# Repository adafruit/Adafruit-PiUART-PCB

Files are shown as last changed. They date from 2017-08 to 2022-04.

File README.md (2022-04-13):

## Adafruit PiUART PCB

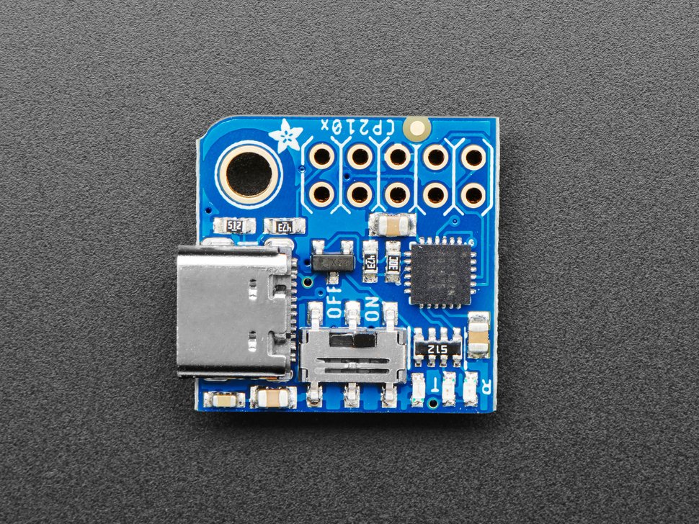
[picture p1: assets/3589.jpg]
<a href="http://www.adafruit.com/products/3589"><br/>
Click here to purchase one from the Adafruit shop</a>

PCB files for the Adafruit PiUART PCB. Format is EagleCAD schematic and board layout

For more details, check out the product page at
* http://www.adafruit.com/product/3589

### Description

Here's another super handy add-on for your Raspberry Pi computer, perfect for 'head-less' setups! The PiUART adds a USB Type-C to serial connection so you can use any serial port software to connect to the Pi's console. It plugs in and is fast and easy to add whenever you need to connect to your Pi. Two LEDs connect to RX and TX on the serial converter chip so you get blinking whenever data is sent or received..

We had some space left over, so the PiUART also comes with an on-off switch with a 4 Amp transistor. You can power your Pi through the USB-C port and then use the switch whenever you want to cut power, without having to unplug the cable. Low-power usage Pi's like the Pi Zero and A+ can thus be powered and controlled from a single cable connected to your computer. Heavy-hitter Pi's like the Pi 2 and Pi 3 may draw too much power from a computer USB port, so check if your motherboard has a high-current USB port before trying.

Comes fully assembled and ready to go, plug into your Pi, and on Mac OS X install the driver - within 2 minutes and you'll be ready to go.

Works with any Raspberry Pi computer (Pi 1, 2, 3, Zero, etc)

### License

Adafruit invests time and resources providing this open source design, please support Adafruit and open-source hardware by purchasing products from [Adafruit](https://www.adafruit.com)!

Designed by Limor Fried/Ladyada for Adafruit Industries.

Creative Commons Attribution/Share-Alike, all text above must be included in any redistribution. See license.txt for additional details.

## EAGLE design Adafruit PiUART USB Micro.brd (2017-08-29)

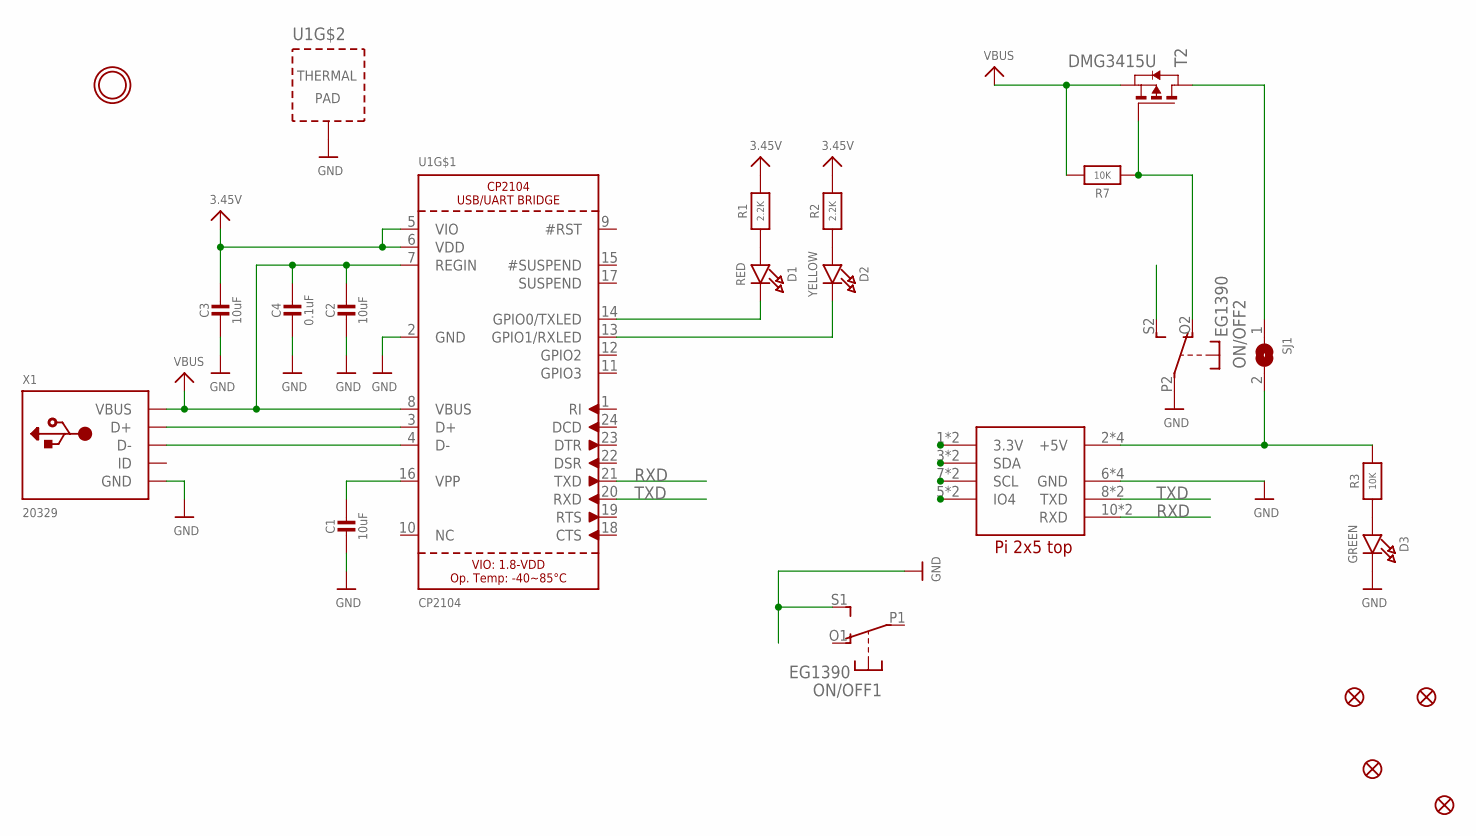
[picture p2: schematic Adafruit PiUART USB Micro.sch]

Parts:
C1, C2, C3: 10uF; 0805-NO
C4: 0.1uF; 0603-NO
D1: RED; CHIPLED_0603_NOOUTLINE
D2: YELLOW; CHIPLED_0603_NOOUTLINE
D3: GREEN; CHIPLED_0603_NOOUTLINE
FID1, FID2, FID3, FID4: FIDUCIAL_1MM
ON/OFF: EG1390
R1, R2: 2.2K; 0603-NO
R3, R7: 10K; 0603-NO
SJ1: SOLDERJUMPERCLOSED; SOLDERJUMPER_CLOSEDWIRE
T2: DMG3415U; SOT-23
U1: CP2104; QFN24_4MM_SMSC
U$9: RASPBERRYPI_2X5; RASPBERRYPI_2X5_THMSMT
U$18: MOUNTINGHOLE3.0THIN; MOUNTINGHOLE_3.0_PLATEDTHIN
X1: 20329; 4UCONN_20329_V2

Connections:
3.3V: C3.1, R1.2, R2.2, U1.5 (VIO), U1.6 (VDD)
GND: C1.2, C2.2, C3.2, C4.2, D3.C, ON/OFF.P2, ON/OFF.S1 (S), U1.2 (GND), U1.THERM (TP), U$9.6 (GND), U$9.6' (GND), U$9.9 (GND), U$9.9' (GND), X1.BASE@1 (GND), X1.BASE@2 (GND), X1.GND, X1.SPRT@1 (GND), X1.SPRT@2 (GND), X1.SPRT@3 (GND), X1.SPRT@4 (GND)
unnamed: D1.A, R1.1
unnamed: U1.3 (D+), X1.D+
unnamed: U1.4 (D-), X1.D-
unnamed: C1.1, U1.16 (VPP)
unnamed: D2.A, R2.1
unnamed: D1.C, U1.14 (GPIO0/TXLED)
unnamed: D2.C, U1.13 (GPIO1/RXLED)
unnamed: U$9.1 (3.3V), U$9.1' (3.3V)
unnamed: U$9.3 (SDA), U$9.3' (SDA)
unnamed: U$9.7 (SCL), U$9.7' (SCL)
unnamed: U$9.5 (IO4), U$9.5' (IO4)
unnamed: R3.2, SJ1.2, U$9.2 (+5V), U$9.2' (+5V), U$9.4 (+5V), U$9.4' (+5V)
unnamed: ON/OFF.O2 (O), R7.1, T2.3 (G)
unnamed: D3.A, R3.1
RXD: U1.21 (TXD), U$9.10 (RXD), U$9.10' (RXD)
TXD: U1.20 (RXD), U$9.8 (TXD), U$9.8' (TXD)
VBUS: C2.1, C4.1, R7.2, T2.2 (S), U1.7 (REGIN), U1.8 (VBUS), X1.VBUS
VIN: SJ1.1, T2.1 (D)

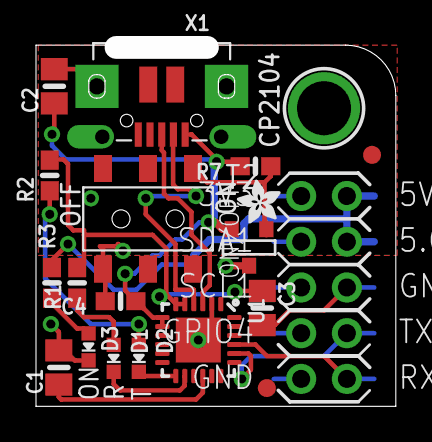
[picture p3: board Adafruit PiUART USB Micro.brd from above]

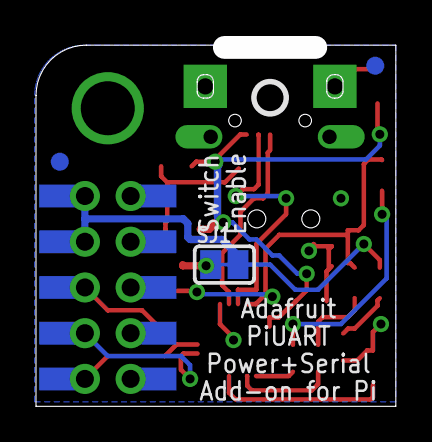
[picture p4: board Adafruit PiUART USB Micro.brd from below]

Board: 2 copper layers, 20.0 x 20.1 mm, 24 parts (4 on the bottom side), 20 nets.

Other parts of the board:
U$8: ADAFRUIT_2.5MM
U$17: PCBFEAT-REV-040

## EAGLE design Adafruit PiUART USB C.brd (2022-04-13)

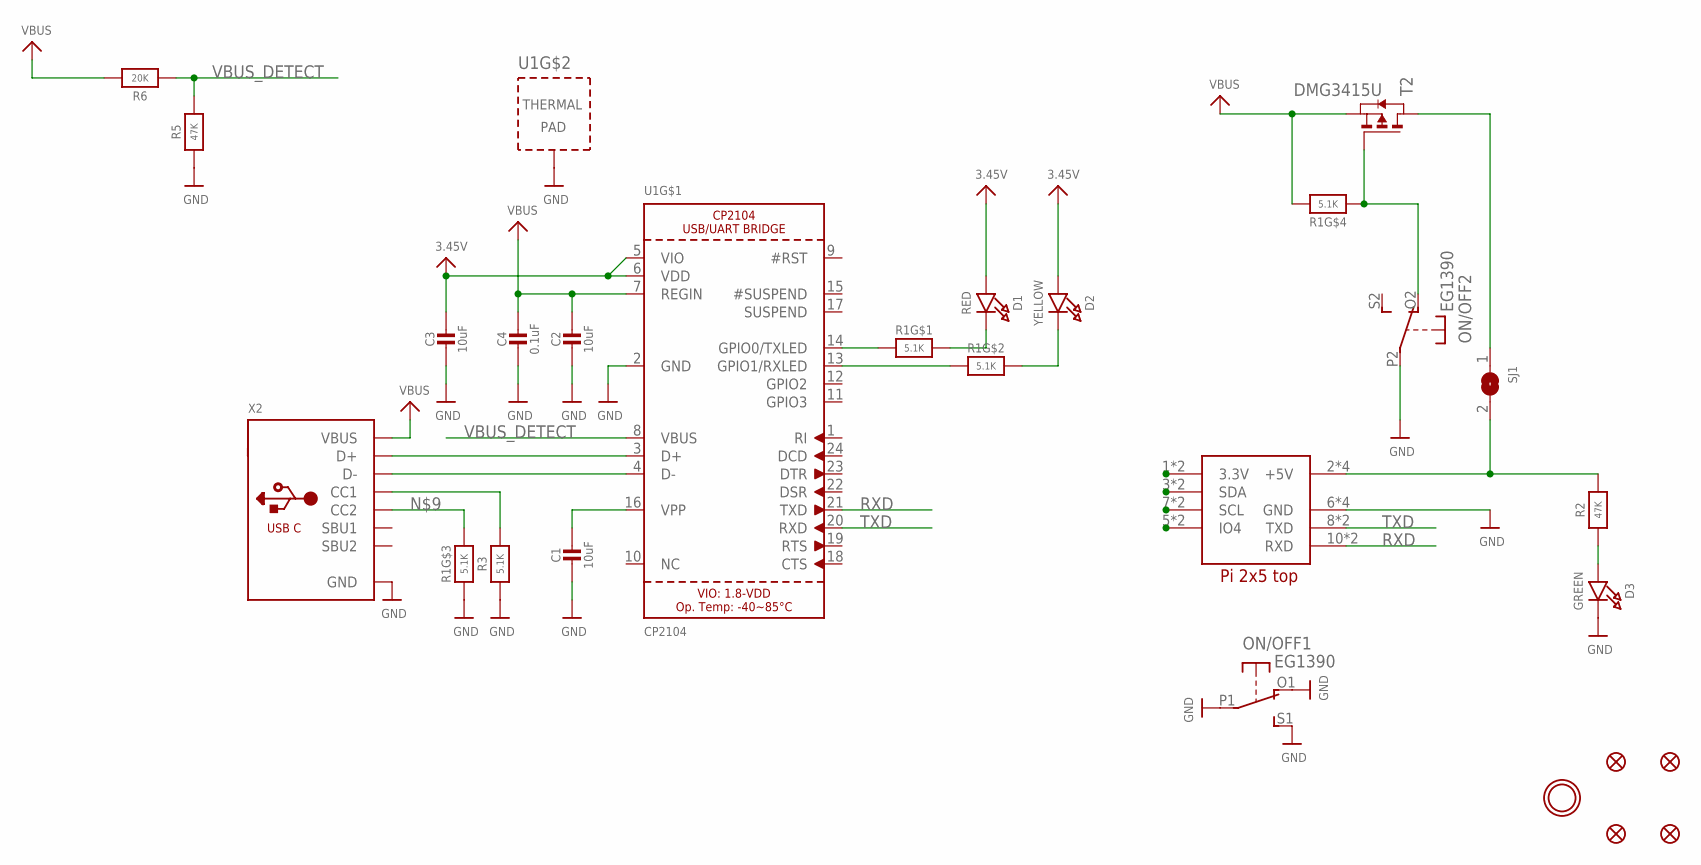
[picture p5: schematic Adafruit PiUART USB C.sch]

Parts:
C1, C2, C3: 10uF; 0805-NO
C4: 0.1uF; 0603-NO
D1: RED; CHIPLED_0603_NOOUTLINE
D2: YELLOW; CHIPLED_0603_NOOUTLINE
D3: GREEN; CHIPLED_0603_NOOUTLINE
FID1, FID2, FID3, FID4: FIDUCIAL_1MM
ON/OFF: EG1390
R1: 5.1K; RESPACK_4X0603
R2, R5: 47K; 0603-NO
R3: 5.1K; 0603-NO
R6: 20K; 0603-NO
SJ1: SOLDERJUMPERCLOSED; SOLDERJUMPER_CLOSEDWIRE
T2: DMG3415U; SOT-23
U1: CP2104; QFN24_4MM_SMSC
U$9: RASPBERRYPI_2X5; RASPBERRYPI_2X5_THMSMT
U$18: MOUNTINGHOLE3.0THIN; MOUNTINGHOLE_3.0_PLATEDTHIN
X2: USB_C; USB_C_CUSB31-CFM2AX-01-X

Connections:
3.3V: C3.1, D1.A, D2.A, U1.5 (VIO), U1.6 (VDD)
5V: R2.2, SJ1.2, U$9.2 (+5V), U$9.2' (+5V), U$9.4 (+5V), U$9.4' (+5V)
GND: C1.2, C2.2, C3.2, C4.2, D3.C, ON/OFF.O1 (O), ON/OFF.P1, ON/OFF.P2, ON/OFF.S1 (S), R1.3 (1), R3.1, R5.1, U1.2 (GND), U1.THERM (TP), U$9.6 (GND), U$9.6' (GND), U$9.9 (GND), U$9.9' (GND), X2.A1B12 (GND), X2.B1A12 (GND)
unnamed: D3.A, R2.1
unnamed: U1.3 (D+), X2.A6 (D+), X2.B6 (D+)
unnamed: U1.4 (D-), X2.A7 (D-), X2.B7 (D-)
unnamed: C1.1, U1.16 (VPP)
unnamed: R1.1, U1.14 (GPIO0/TXLED)
unnamed: D1.C, R1.8 (2)
unnamed: R1.2 (1), U1.13 (GPIO1/RXLED)
unnamed: D2.C, R1.7 (2)
unnamed: R1.6 (2), X2.B5 (CC2)
unnamed: R3.2, X2.A5 (CC1)
unnamed: ON/OFF.O2 (O), R1.4 (1), T2.3 (G)
NC1: U$9.1 (3.3V), U$9.1' (3.3V)
NC2: U$9.3 (SDA), U$9.3' (SDA)
NC3: U$9.5 (IO4), U$9.5' (IO4)
NC4: U$9.7 (SCL), U$9.7' (SCL)
RXD: U1.21 (TXD), U$9.10 (RXD), U$9.10' (RXD)
TXD: U1.20 (RXD), U$9.8 (TXD), U$9.8' (TXD)
VBUS: C2.1, C4.1, R1.5 (2), R6.2, T2.2 (S), U1.7 (REGIN), X2.A4B9 (VBUS), X2.B4A9 (VBUS)
VBUS_DETECT: R5.2, R6.1, U1.8 (VBUS)
VIN: SJ1.1, T2.1 (D)

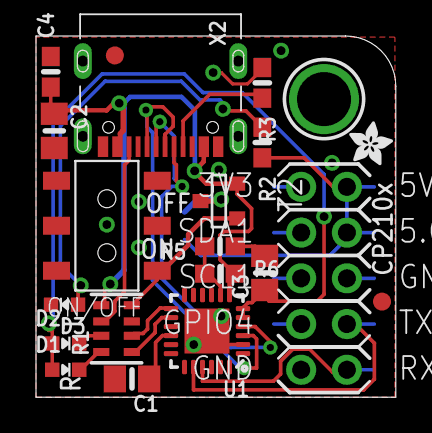
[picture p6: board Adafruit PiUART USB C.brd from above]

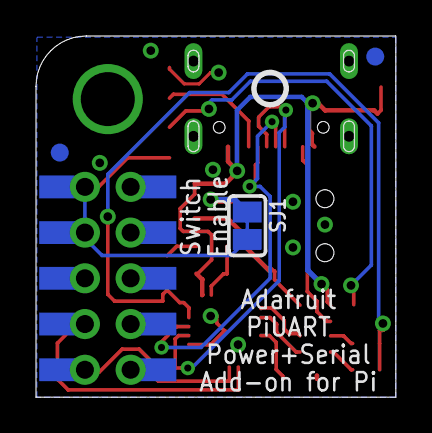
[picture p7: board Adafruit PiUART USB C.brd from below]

Board: 2 copper layers, 20.0 x 20.1 mm, 25 parts (4 on the bottom side), 23 nets.

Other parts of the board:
U$8: ADAFRUIT_2.5MM
U$17: PCBFEAT-REV-040

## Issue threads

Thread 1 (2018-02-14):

Not recognised by Windows 10

jonnygoldengonads, 2018-02-14:
My unit refuses to work with Windows 10, I have tried 2 separate PC's, 3 different Pis and a number of USB cables. At no point is the unit recognised.

It powers the Pi and I get a green LED.

I have enabled Shell/Serial as per instructions.

Is this a known issue? The only documentation I can find for Windows seems to cover XP.

ladyada, 2018-02-14:
hiya please use the adafruit forums for tech support :)

jonnygoldengonads, 2018-02-14:
Any chance of a link, I'm not familiar with your forums. Thanks.

ladyada, 2018-02-14:
https://forums.adafruit.com/

Closed 2018-02-14.

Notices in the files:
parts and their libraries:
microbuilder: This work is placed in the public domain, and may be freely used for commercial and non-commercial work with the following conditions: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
